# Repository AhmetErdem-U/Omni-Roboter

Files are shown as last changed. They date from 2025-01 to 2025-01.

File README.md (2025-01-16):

# **Omni-Roboter: Entwicklung eines Prototypen mit Omni-Ball-Antrieb**

## 🎯 **Projektbeschreibung**
Dieses Projekt beinhaltet die Entwicklung eines Prototyp-Roboters mit omnidirektionalem Antrieb. Der Roboter nutzt die **Omni-Ball-Technologie**, die Bewegungen in alle Richtungen ermöglicht. Das Projekt kombiniert **CAD-Konstruktion**, **3D-Druck** und **Arduino-Programmierung**, um einen funktionsfähigen Prototypen zu erstellen, der für Anwendungen in der Robotik und Automatisierung geeignet ist.

---

## 🚀 **Hauptfunktionen**
- **Omnidirektionale Bewegung:** Nahtlose Steuerung in alle Richtungen dank Omni-Ball-Technologie.
- **CAD-Konstruktion:** Präzises Design und Simulation mit Autodesk Fusion 360.
- **3D-Druck:** Mechanische Komponenten wurden aus PETG gefertigt, um eine robuste und leichte Struktur zu gewährleisten.
- **Arduino-Steuerung:** Programmierung der Motoren und Steuerlogik mit der Arduino-IDE.
- **Bluetooth-Integration:** Fernsteuerung des Roboters über ein Bluetooth-Modul.

---

## 🛠️ **Technische Details**

### **Hardware**
- **Arduino Mega 2560**
- **NEMA-17 Schrittmotoren**
- **Omni-Ball-Räder**
- **HC-05 Bluetooth-Modul**
- **LiPo-Akku**
- **RAMPS 1.4 Shield Board**

### **Software**
- **Autodesk Fusion 360:** Konstruktion der mechanischen Bauteile.
- **Arduino IDE:** Steuerung und Bewegungslogik.
- 
---

## 📸 **Bilder**

### **1. Omni-Fahrzeug**
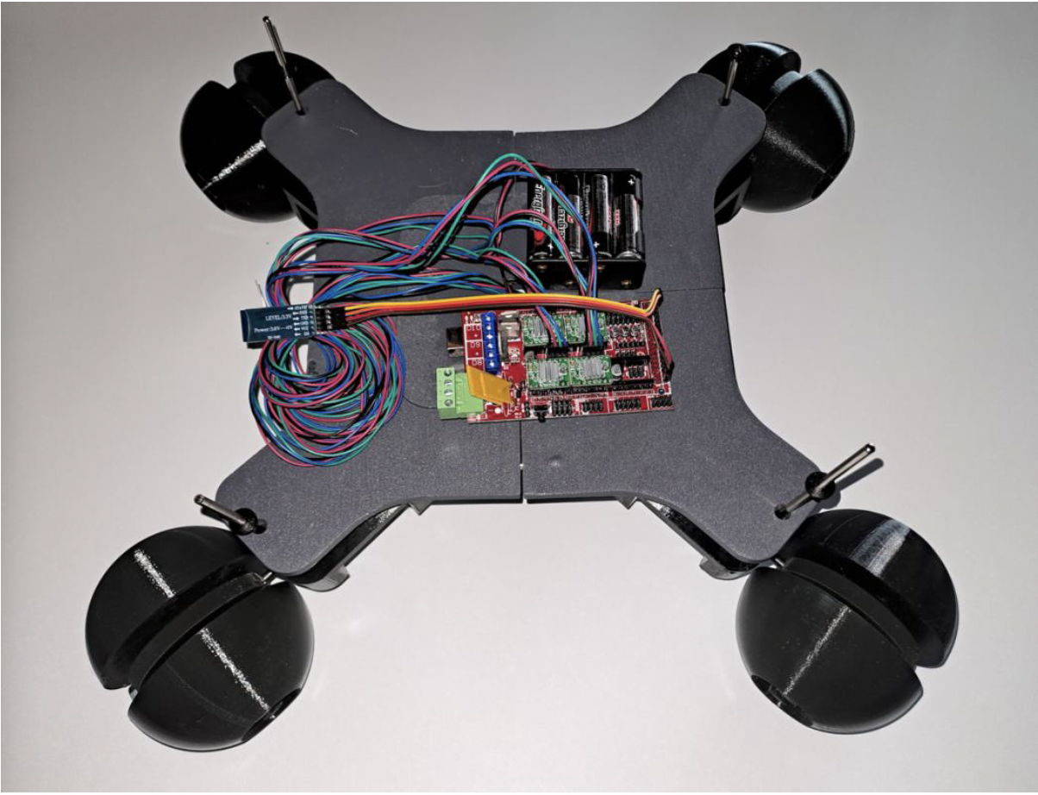
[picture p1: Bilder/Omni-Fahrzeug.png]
Omni-Roboter Bewegung


### **2. Halterung**
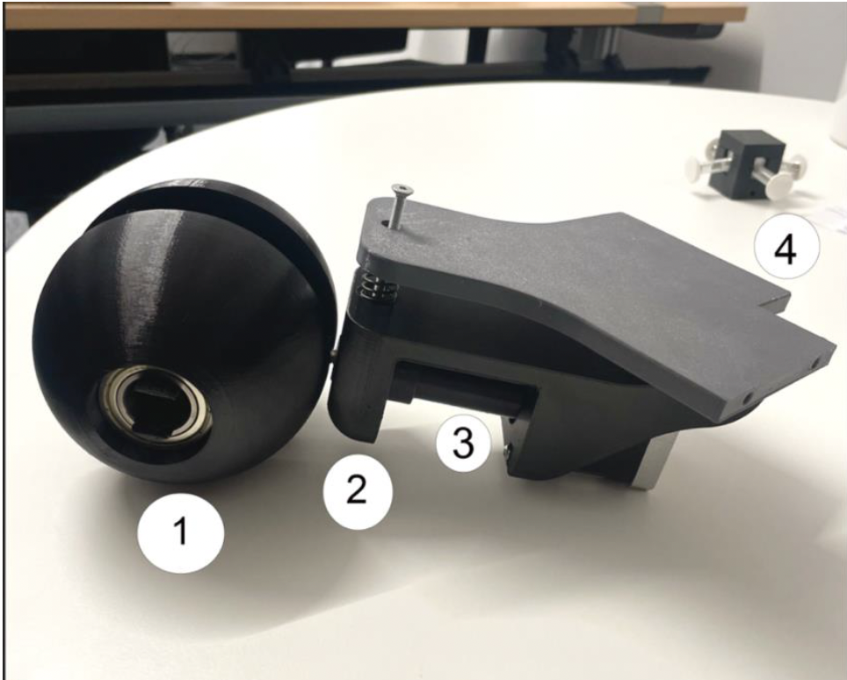
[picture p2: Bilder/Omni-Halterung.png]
Omni-Fahrzeug


### **3. Bewegungs-Verhalten**
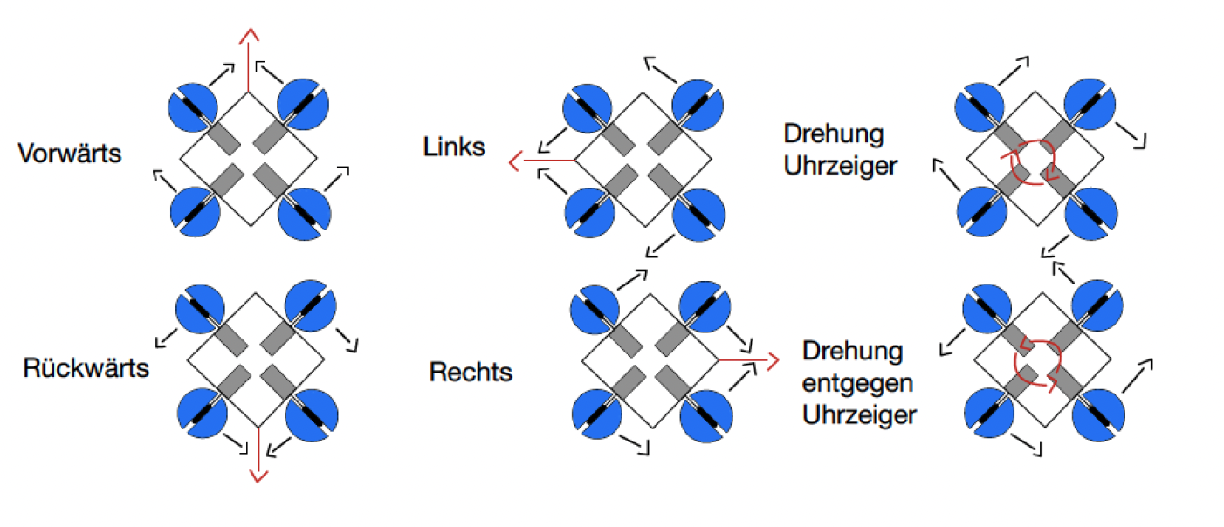
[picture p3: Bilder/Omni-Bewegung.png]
Omni Bewegung


### **4. Mechanische Details**
- **Kleine Kugel:**
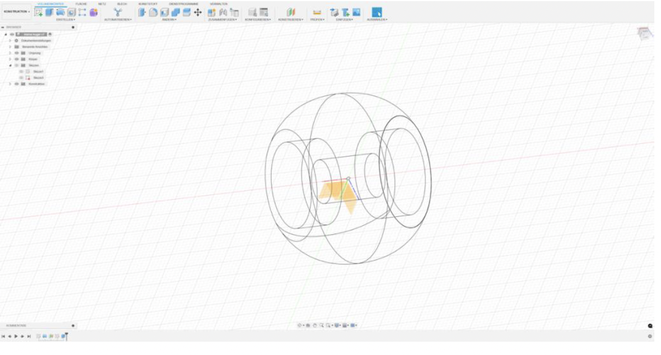
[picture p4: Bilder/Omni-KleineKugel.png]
Kleine Kugel
  

- **Hauptkugel:**
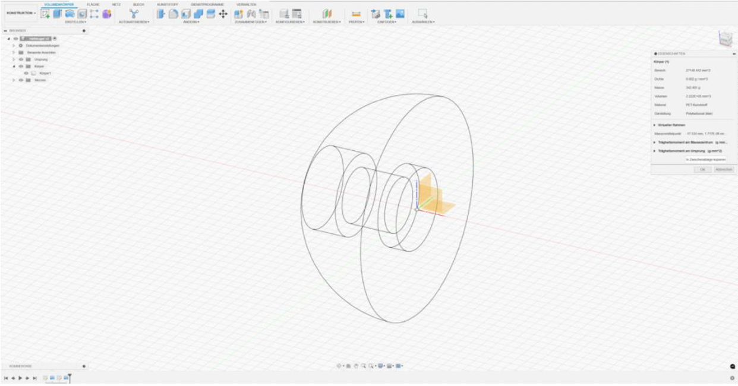
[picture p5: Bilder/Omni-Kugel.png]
Hauptkugel
  
  
- **Welle:**
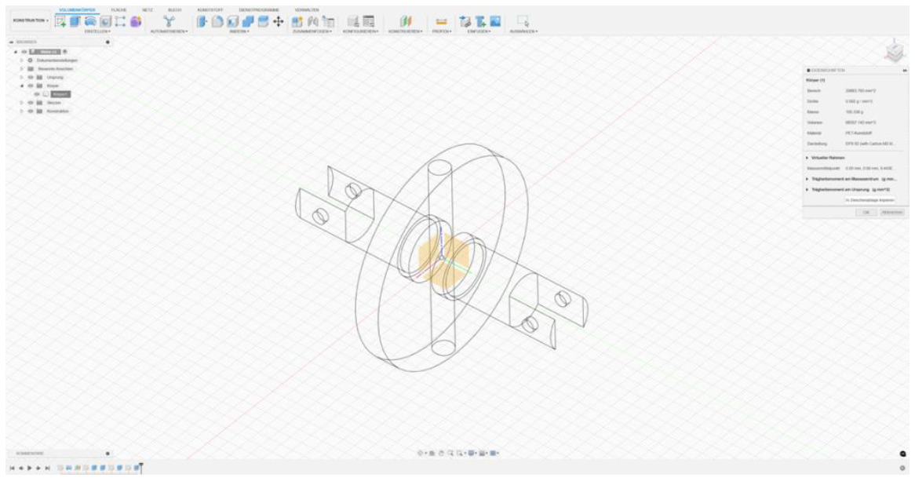
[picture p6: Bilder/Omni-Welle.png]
Welle
  

### **5. Verkabelung**
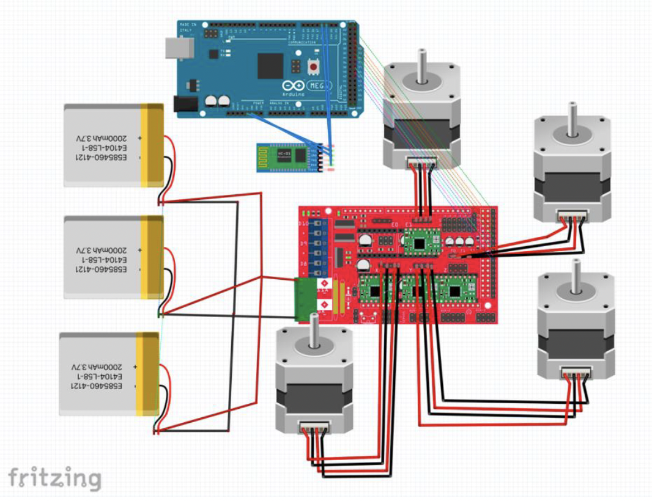
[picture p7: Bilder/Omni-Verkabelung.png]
Verkabelung


---

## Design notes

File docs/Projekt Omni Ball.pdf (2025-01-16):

Projekt Omni Ball

Komponenten für mein Projekt-Omni Ball

Mechanische Komponenten

Bauteil | Material | Abmessungen | Anzahl | Funktion
Halbkugeln | PTG (3D-gedruckt) | Durchmesser: 100 mm | 8 (jeweils 2 pro Omni-Ball) | Ermöglichen omnidirektionale Bewegung
Kleine Kugeln | PTG (3D-gedruckt) | Passend zur Oberseite der Halbkugeln | 8 (jeweils 2 pro Omni-Ball) | Unterstützung für die Halbkugeln
Welle | Edelstahl oder Aluminium | Durchmesser: 20 mm | 4 (jeweils 1 pro Omni-Ball) | Verbindung der Halbkugeln
Lager für Halbkugeln | Stahl | 37 x 20 x 9 mm | 16(jeweils 4 pro Welle) | Ermöglichen reibungslose Rotation
Lager für kleine Räder | Stahl | 10 x 5 x 4 mm | 16 (jeweils 4 pro Rad ) | Ermöglichen reibungslose Rotation
Motorhalterungen | PTG (3D-gedruckt) | Durchmesser: 42 mm | 4 (jeweils 1 pro Motor) | Befestigung der Motoren
Zahnräder (klein) | PTG (3D-gedruckt) | 12 Zähne, Durchmesser ca. 40 mm | 4 (jeweils 1 pro Motor) | Kraftübertragung vom Motor
Zahnräder (groß) | PTG (3D-gedruckt) | 30 Zähne, Durchmesser ca. 100 mm | 4 (jeweils 1 pro Welle) | Kraftübertragung zur Welle

Elektronische Komponenten

Bauteil | Typ | Spezifikationen | Anzahl | Funktion
Motoren | NEMA 17 | N/A | 4 (jeweils 1 pro Omni-
Ball)
| | | | Antrieb der Omni-Bälle

Motorsteuerungen | A4988 Motor-Treiber | N/A | 4 (jeweils 1 pro Motor) | Steuerung der Schrittmotoren
Batterien | LIPO | Spannung: 11.1V, Kapazität: 2200mAh | 3 (parallel geschaltet) | Stromversorgung
Batterie-Ladegerät | SKYRC B6AC V2 | | 1 | Ladung der Batterie
Batterie-Management | 3S 20A Li-ion Lithium Batterie BMS | | 1 | Schutz der Batterien
Arduino-Board | Arduino Mega | N/A | 1 | Zentrale Steuerungseinheit
Bluetooth-Modul | HC-05 | N/A | 1 | Drahtlose Kommunikation
Shield Board | RAMPS 1.4 Shield Board | | 1 | Erweiterung für Arduino Mega

Verbindungskomponenten

Bauteil | Typ | Spezifikationen | Anzahl | Funktion
Kabel und Steckverbinder | Jumper-Kabel, Steckverbinder | N/A | Ausreichend | Verbindungen zwischen Komponenten
Befestigungsmaterial | Schrauben, Muttern, Bolzen | N/A | Ausreichend | Befestigung der mechanischen Komponenten

Zusätzliche Materialien und Werkzeuge

Bauteil | Material/Typ | Spezifikationen Anzahl | Funktion
3D-Drucker | ABS | N/A | N/A | Herstellung von 3D-gedruckten Teilen
Superkleber | N/A | N/A | 1 Tube | Fixierung der Zahnräder an den Wellen
Werkzeuge | Schraubendreher, Zangen, Messschieber, etc. | N/A | 1 Satz | Montage der mechanischen und elektronischen Komponenten

## Vorschlag von Herr Frank: Nema Motor-Schrittmotor

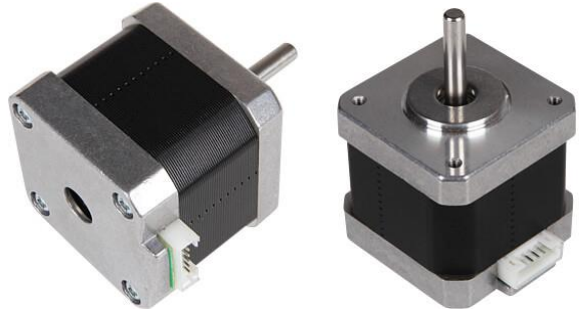
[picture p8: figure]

NEMA 17 Schrittmotor

1. Spezifikationen:
- Haltenmoment: 4.2 kg-cm (42 Ncm)
- Betriebsspannung: 12-24V
- Nennstrom: 1.2A pro Phase
- Schrittwinkel: 1.8° (200 Schritte pro Umdrehung)
- Wellenlänge: 24 mm
- Wellen-Durchmesser: 5 mm
- Abmessungen: 42 x 42 x 48 mm
2. Anzahl:
- 4 (jeweils 1 pro Omni-Ball)
3. Vorteile:
- Präzise Steuerung der Position
- Hohe Wiederholgenauigkeit
- Gute Kompatibilität mit Arduino und gängigen Treibern
4. Kompatibler Treiber:

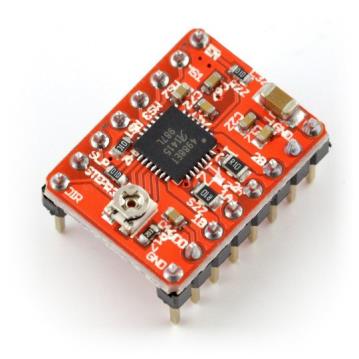
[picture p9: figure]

- A4988 Schrittmotortreiber
- Anzahl: 4 (jeweils 1 pro NEMA 17 Motor)
- Betriebsspannung: 8-35V
- Maximaler Strom: 2A pro Spule
- Microstepping: Bis zu 1/16 Schritte

Anpassungen an der Konstruktion

1. Motorhalterungen:
- Die Motorhalterungen müssen angepasst werden, um die Abmessungen des NEMA 17 Motors aufzunehmen (42 x 42 mm).
2. Zahnräder:
- Das Zahnrad für den Motor muss auf die 5 mm Welle des NEMA 17 Motors passen.
3. Elektrische Verdrahtung:
- Schrittmotortreiber (z.B. A4988) müssen in das elektrische System integriert werden, um die NEMA 17 Motoren zu steuern.

## 4. Verschiedene Batterie-Typen für das Projekt im Vergleich:

Batterietyp | Energiedichte | Lebensdauer | Sicherheit | Gewicht | Kosten
LiPo | Hoch | Mittel | Mittel | Gering | Mittel
Li-Ion | Hoch | Hoch | Hoch | Mittel | Hoch
NiMH | Niedrig | Hoch | Hoch | Hoch | Niedrig
LiFePO4 | Mittel | Sehr hoch | Sehr hoch | Mittel | Hoch
Fazit: Auswahl einer
Lipo-Batterie

5.

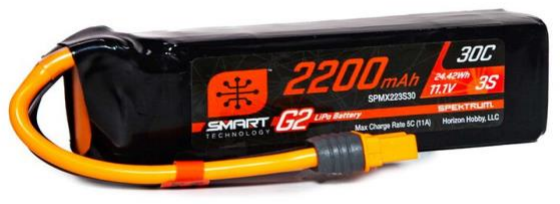
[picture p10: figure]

6. 11.1V 2200mAh 3S 30C Smart G2 LiPo Battery: IC3
7.

## 8. Arduino-Board wird von Herr Frank ausgesucht 9. Wie kann man zusätzlich eine Bluetooth Verbindung herstellen?

10. HC-05 Bluetooth-Modul: Drahtlose Kommunikation

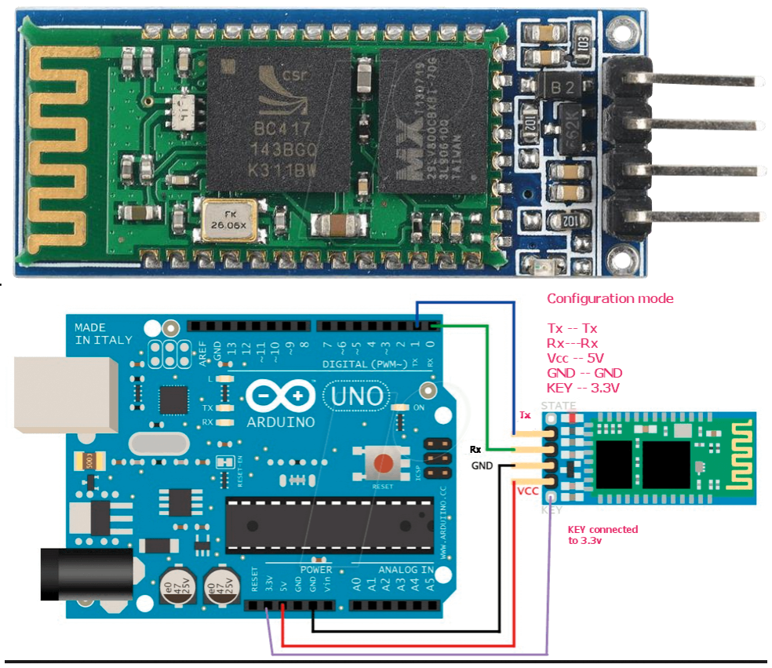
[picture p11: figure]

11.

12. ARDUINO HC-05-4 Arduino - 4duino Wireless Modul HC-05 4-Pin

Gewichtsberechnung meines Projektes

Komponente | Material/Art | Volumen (cm³) | Dichte (g/cm³) | Anzahl | Gewicht pro Einheit (g) Gesamtgewicht (g)
Omni-Ball (Halbkugeln und kleine Kugeln) | PTG (3D-gedruckt) | 313,16 | 1,04 | 4 | 325,68 | 1302,72
Welle + Stahlrohr | PTG ( 3D- gedruckt ), Sthal | 15,71 | 2,70 | 4 | 42,42 | 169,68
Lager Halbkugeln | Stahl | 10 | 7,85 | 8 | 78,5 | 628
Lager kleine Kugel | Stahl
Motoren | NEMA-17 Schrittmotor | - | - | 4 | 350 | 1400
Elektronik (Arduino, HC-05, A4988,Ramps 1.4) | Verschiedene | - | - | - | - | 300
Batterien | LiPo-Batterie (11.2V) | - | - | 2 | 500 | 1000
Kabel und Steckverbinder | Verschiedene | - | - | Ausreichend | - | 200
Befestigungsmaterial Verschiedene | | - | - | Ausreichend | - | 100
- Omni-Ball (Halbkugeln und kleine Kugeln)

- Volumen der Halbkugel:
- Das Volumen einer Halbkugel mit einem Radius von 50 mm (Durchmesser 100 mm) beträgt ca. 261,8 cm³.
- Volumen der kleinen Kugeln:
- Jede Halbkugel hat eine kleine Kugel. Ein Omni-Ball hat zwei kleine Kugeln. Wenn jede kleine Kugel 10% des Volumens einer Halbkugel hat, beträgt das Volumen jeder kleinen Kugel ca. 26,18 cm³. Somit hat ein Omni-Ball zwei kleine Kugeln mit einem Gesamtvolumen von ca. 52,36 cm³.

Gesamtvolumen des Omni-Balls:

- Das Gesamtvolumen einer Halbkugel und der kleinen Kugeln beträgt insgesamt ca. 313,16 cm³.
- Welle
- Volumen der Welle:
- Eine Welle mit einem Durchmesser von 20 mm und einer Länge von 50 mm hat ein Volumen von ca. 15,71 cm³.
- Zahnräder
- Volumen der Zahnräder:
- Das Volumen der kleinen Zahnräder wurde auf 20 cm³ und das der großen Zahnräder auf 40 cm³ festgelegt.

Berechnungen für den NEMA 17 Schrittmotor

Auf Basis der Präsentation „Wahlfach – Alternativ angetriebene Fahrzeuge“ und der Spezifikationen des NEMA 17 Schrittmotors, führen wir die relevanten Berechnungen für das Projekt durch.

### 1. Berechnung der Rollwiderstandskraft (FR)

Die Rollwiderstandskraft FR kann durch die Formel berechnet werden:

FR = m ∙ g ∙ froll

Für den NEMA 17 Schrittmotor und das Omni-Ball-Projekt benötigen wir die Masse des Systems:

- Masse des Systems (m): Nehmen wir an, die Masse beträgt 5.558 kg (5.558 kg = 5558 g / 1000).
- Gravitationskonstante (g): 9,81 m/s²
- Rollwiderstandsbeiwert (froll): Angenommen 0,015 für glatte Oberflächen.

Berechnung:

FR = 5,558 kg ∙

9,81m
s

2

- 0,015 = 0,819 N

### 2. Berechnung der Luftwiderstandskraft (FW)

Die Luftwiderstandskraft FW wird mit der Formel berechnet:

FW =

1
2
- p ∙ cW ∙ A ∙ v

2

Wir benötigen:

- Luftdichte (ρ): 1,202 kg/m³
- Luftwiderstandsbeiwert (cw): 0,3 (angenommen)
- Stirnfläche des Fahrzeugs (A): 0,1 m² (angenommen)
- Geschwindigkeit (v): 1 m/s (als Beispiel)

Berechnung:

FW =

1
2
- 1,202

kg
m³
- 0,3 ∙ 0,1m²
- (

1m
s

)

2
= 0,018 N

### 3. Berechnung der Steigungswiderstandskraft (Fsteig)

Die Steigungswiderstandskraft Fsteig wird berechnet mit:

Fsteig = m ∙ g ∙ sin (α)

Für eine Steigung von 10%:

- Steigungswinkel (α): tan⁻¹ (0,1) = 5,71°

Berechnung:

Fsteig = 5,558 kg ∙

9,81m
s

2

- sin(5,71°) = 5,42 N

### 4. Berechnung der Beschleunigungskraft (Fa)

Die Beschleunigungskraft Fa wird mit der Formel berechnet:

Fa = m ∙ a

- Beschleunigung (a): Angenommen 0,5 m/s²

Berechnung:

Fa = 5,558 kg ∙ 0,5

m
s

2

= 2,78 N

### 5. Gesamtantriebskraft (FA)

Die Gesamtantriebskraft FA ist die Summe der Widerstände:

FA = FR + FW + Fsteig + Fa

Berechnung:

FA = 0,819 N + 0,018 N + 5,42 N + 2,78N = 9,037 N

### 6. Antriebsmoment (MA)

Das Antriebsmoment MA wird mit der Formel berechnet:

MA = FA ∙ r

Rollradius (r): 0,05 m (angenommen) ,was auf dem Radius der Halbkugel basiert.

Berechnung:

MA = 9,037 N ∙ 0,05 m = 0,45185 Nm

### 7. Antriebsleistung (P)

Die Antriebsleistung P wird mit der Formel berechnet:

P = FA ∙ v

- Geschwindigkeit (v): 1 m/s

Berechnung:

P = 9,037 N ∙

1m
s

= 9,037 W

Fazit zur Eignung des NEMA 17 Schrittmotors für das Projekt

Auf Grundlage der durchgeführten Berechnungen und der technischen Daten des NEMA 17 Schrittmotors, lassen sich folgende Schlüsse ziehen:

Zusammenfassung der Berechnungen:

- Rollwiderstandskraft (FR): 0,819 N
- Luftwiderstandskraft (FW): 0,018 N
- Steigungswiderstandskraft (Fsteig): 5,42 N
- Beschleunigungskraft (Fa): 2,78 N
- Gesamtantriebskraft (FA): 9,037 N
- Antriebsmoment (MA): 0,45185 Nm
- Antriebsleistung (P): 9,037 W

Technische Spezifikationen des NEMA 17 Schrittmotors:

- Haltemoment: 4,2 kg-cm (42 Ncm oder 4,2 Nm)
- Betriebsspannung: 12-24V
- Nennstrom: 1,2A pro Phase
- Schrittwinkel: 1,8° (200 Schritte pro Umdrehung)
- Abmessungen: 42 x 42 x 48 mm

Analyse der Eignung:

1. Antriebsmoment:
- Das berechnete Antriebsmoment von 0,45185 Nm liegt deutlich unter dem Haltemoment des NEMA 17 Schrittmotors von 4,2 Nm. Dies bedeutet, dass der Motor ausreichend Kraft hat, um die erforderlichen Bewegungen auszuführen.

2. Antriebsleistung:
- Die erforderliche Antriebsleistung von 9,037 W ist relativ gering im Vergleich zu den typischen Leistungsfähigkeiten des NEMA 17 Motors, der bei den angegebenen Spannungen und Strömen wesentlich höhere Leistungen liefern kann.
3. Betriebsspannung und Nennstrom:
- Die Betriebsspannung und der Nennstrom des NEMA 17 Motors sind geeignet für den Einsatz mit den geplanten elektronischen Komponenten wie dem Arduino und den LiPo-Batterien.
4. Schrittwinkel und Präzision:
- Mit einem Schrittwinkel von 1,8° und der Möglichkeit, Mikroschritte zu nutzen, bietet der NEMA 17 Motor eine hohe Präzision und Kontrolle, die für die präzise Steuerung der Omni-Bälle wichtig ist.

Fazit:

Der NEMA 17 Schrittmotor ist ausreichend leistungsfähig und gut geeignet für das Projekt „Omni-Ball“. Er bietet ausreichend Drehmoment und Leistung, um die erforderlichen Bewegungen und Kräfte zu bewältigen. Die technischen Spezifikationen des Motors passen gut zu den Anforderungen des Projekts und den geplanten elektronischen Komponenten.

## Erweiterter Ansatz anhand eines Ramps

Methode 2: RAMPS 1.4 Shield Board mit A4988 Motor-Treiber

Komponenten:

- RAMPS 1.4 Shield: Ein Erweiterungsboard für das Arduino Mega, das speziell für die Steuerung von Schrittmotoren in 3D-Druckern entwickelt wurde. Es unterstützt bis zu fünf Pololu-Schrittmotortreiber (z.B. A4988).

A4988 Motor-Treiber: Vier Stück zur Steuerung der Schrittmotoren. Zusätzliche Kühlung der Motortreiber durch Kühlkörper alu

Vorteile:

- Integrierte Lösung: Das RAMPS 1.4 Shield vereinfacht die Verkabelung und den Anschluss der Motor-Treiber erheblich.
- Modularität: Einfacher Austausch und Upgrades der Schrittmotor-Treiber.
- Unterstützung für mehrere Motoren: Speziell für Projekte wie 3D-Drucker entwickelt, die mehrere Motoren benötigen.

Nachteile:

- Zusätzliche Komplexität bei der Programmierung: Erfordert ein Verständnis des RAMPS-Boards und möglicherweise Anpassungen an der Firmware.
- Größe: Größer als einige alternative Lösungen aufgrund des zusätzlichen Shields.

Warum ein Arduino Mega 2560 notwendig ist:

1. Kompatibilität: Das RAMPS 1.4 Shield ist speziell für das Arduino Mega 2560 entwickelt worden und passt direkt auf dieses Board.
2. I/O-Pins: Das Arduino Mega 2560 bietet genügend I/O-Pins, um alle Funktionen des RAMPS 1.4 Shields zu nutzen.
3. Leistung: Das Arduino Mega 2560 hat genügend Speicher und Rechenleistung, um komplexe Steuerungsaufgaben zu bewältigen, die mit mehreren Schrittmotoren und anderen Komponenten verbunden sind.

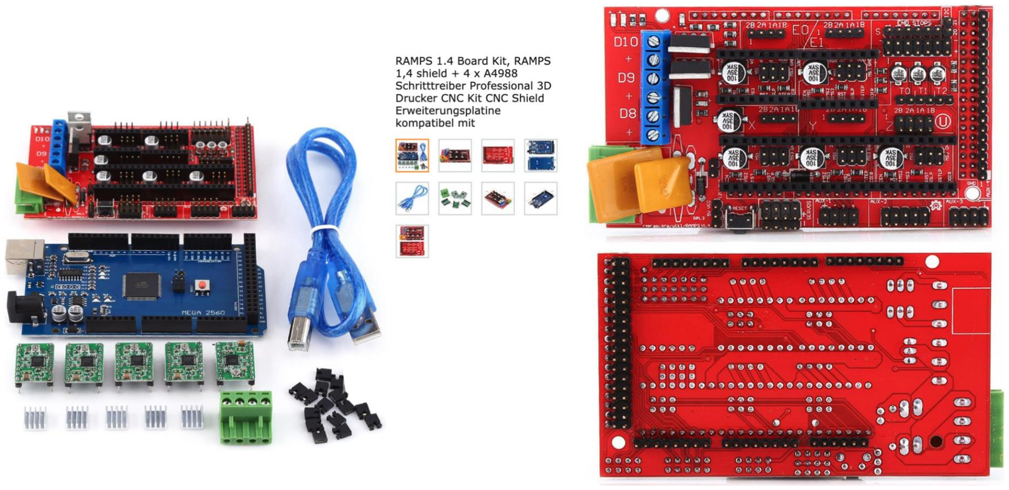
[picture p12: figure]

## Welche Lipo Batterie ist erforderlich

Anforderungen der NEMA 17 Schrittmotoren und A4988 Treiber:

- Betriebsspannung des NEMA 17: Normalerweise 12-24V.
- Strombedarf: Der NEMA 17 Schrittmotor zieht typischerweise bis zu 2A pro Phase.
- A4988 Motor-Treiber: Unterstützt eine Betriebsspannung von 8-35V und kann bis zu 2A pro Spule liefern.

Empfehlungen für LiPo-Batterien:

1. Spannung:
- Um eine Spannung innerhalb des Bereichs von 12-24V zu erreichen, könntest du zwei 3S (11.1V) oder zwei 4S (14.8V) LiPo-Batterien in Serie schalten.
- Die Serienverbindung von zwei 3S-Batterien ergibt eine Gesamtspannung von 22.2V, was innerhalb der sicheren Betriebsparameter für die A4988 Treiber liegt.
2. Kapazität:
- Die Kapazität der Batterie bestimmt, wie lange dein System betrieben werden kann. Eine Kapazität von 2200mAh oder höher wäre angemessen, um eine akzeptable Betriebsdauer zu gewährleisten.
3. Entladungsrate (C-Rate):
- Die Entladungsrate (C-Rate) sollte hoch genug sein, um den Strombedarf deines Systems zu decken. Eine C-Rate von 20C oder höher sollte ausreichen.

Beispielhafte Auswahl:

1. 3S (11.1V) 2200mAh 30C LiPo-Batterie:
- Spannung: 11.1V
- Kapazität: 2200mAh
- Entladungsrate: 30C
- Anzahl: 3 in Serie für 22.2V

Ladegrät: SKYRC B6AC V2

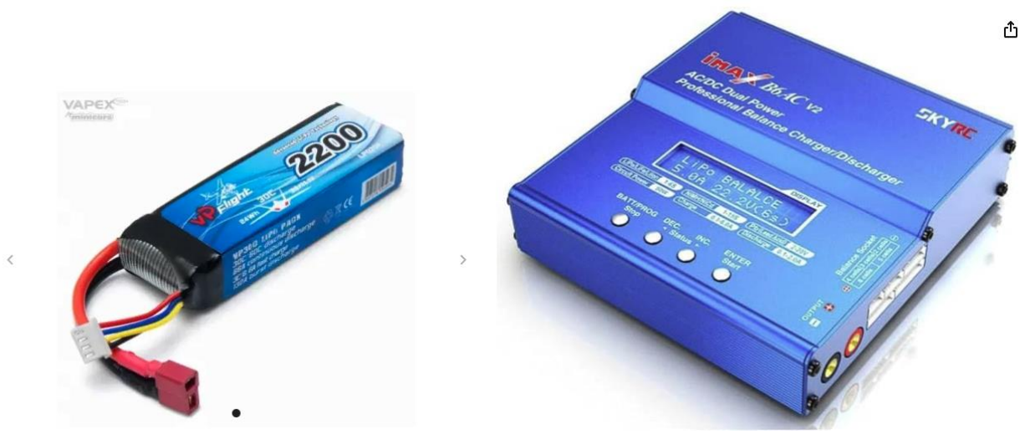
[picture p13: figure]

Vorteile des 3S 20A Li-ion Lithium BMS:

- Schutzfunktionen: Bietet Schutz vor Überladung, Tiefentladung, Überstrom und Kurzschluss.
- Balancer-Funktion: Stellt sicher, dass die Spannung der einzelnen Zellen ausgeglichen wird, um die Lebensdauer der Batterien zu maximieren.
- Stromkapazität: Unterstützt bis zu 20A, was für dein Projekt mit NEMA 17 Schrittmotoren und A4988 Motor-Treibern ausreichend sein sollte.

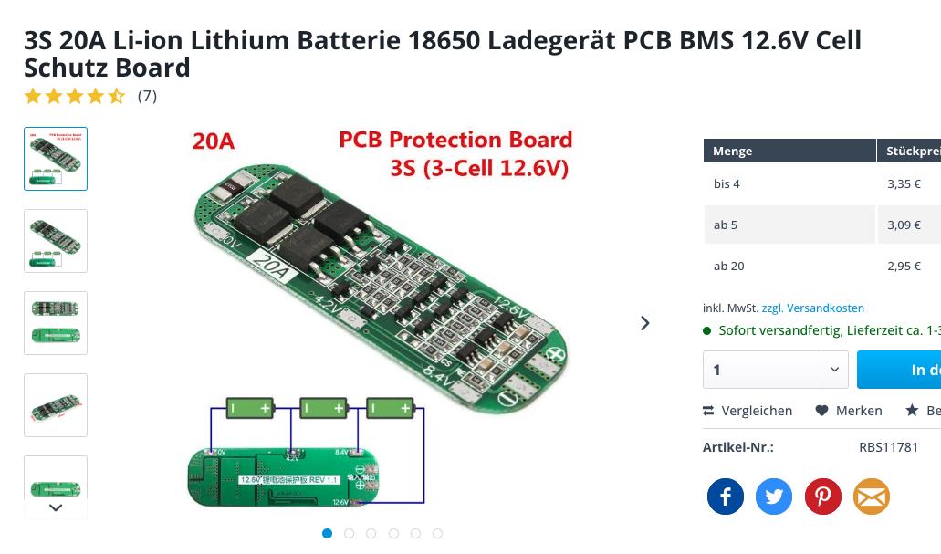
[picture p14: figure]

Ein einzelnes 3S-Batteriepaket (drei in Serie geschaltete 3S 11.1V 2200mAh 30C LiPo-Batterien) kann die Anforderungen des Systems erfüllen, aber die Laufzeit wäre begrenzt

Leistungsanforderungen:

- Einzelner NEMA 17 Schrittmotor: Bis zu 2A pro Phase, maximal 4A pro Motor.
- Vier NEMA 17 Schrittmotoren: 4 Motoren x 4A= 16 A

Batterie-Kapazität:

- 3S 11.1V 2200mAh 30C LiPo-Batterie:
- Nennspannung: 11.1V
- Maximale Spannung: 12.6V
- Kapazität: 2200mAh (2.2Ah)
- Entladestrom: 2200mAh x 30C = 66A

Laufzeitberechnung:

- Kapazität: 2200mAh (2.2Ah)
- Gesamtstrombedarf: 16A

Laufzeit=Kapazität/Gesamt-Strom = 2,2 Ah / 16 A = 0,1375 Stunden = 8,25 Minuten

Fazit:

Ein einzelnes 3S-Batteriepaket wäre in der Lage, die vier NEMA 17 Schrittmotoren zu betreiben, jedoch nur für eine sehr kurze Zeit von etwa 8 Minuten bei voller Last.

Empfehlungen / Verbesserung:

Um eine längere Laufzeit zu erreichen, wäre es sinnvoll, mehrere 3S-Batteriepakete parallel zu schalten. Jede zusätzliche Parallelschaltung verdoppelt die Kapazität und damit die Laufzeit.

Komponenten für ein 3S-Batteriepaket:

1. 3 x 3.7V Li-ion oder LiPo-Zellen: Jede Zelle hat eine Nennspannung von 3.7V und eine Kapazität von 2200mAh (2.2Ah).
- Produkt: 3S 11.1V 2200mAh 30C LiPo-Batterien
- Einkaufsquelle: 3S 11.1V 2200mAh 30C LiPo-Batterien auf Amazon

2. 1 x 3S 20A Li-ion Lithium Batterie BMS: Das BMS verwaltet die Ladung und den Entladestrom und schützt die Batterien vor Überladung, Tiefentladung und Kurzschluss.
- Produkt: 3S 20A Li-ion Lithium Batterie BMS
3. SKYRC B6AC V2 Ladegerät:

Komponentenliste:

1. 4 NEMA 17 Motoren
2. 4 A4988 Motortreiber
3. 1 RAMPS 1.4 Shield Board
4. 1 Arduino Mega
5. 3 3S 11.1V 2200mAh 30C LiPo-Batterien
6. 1 3S 20A Li-ion Lithium Batterie BMS
7. 1 SKYRC B6AC V2 Ladegerät

Überprüfung der Kompatibilität und Funktionalität:

1. NEMA 17 Motoren:
- Betriebsspannung: 12-24V
- Strombedarf: Bis zu 2A pro Phase, maximal 4A pro Motor
2. A4988 Motortreiber:
- Betriebsspannung: 8-35V
- Stromhandling: Bis zu 2A pro Phase (mit Kühlung)
3. RAMPS 1.4 Shield Board:
- Kompatibilität: Entwickelt für das Arduino Mega 2560
- Anschlüsse: Unterstützt bis zu 5 Schrittmotor-Treiber

4. Arduino Mega:
- Kompatibilität: Kompatibel mit RAMPS 1.4 Shield
- Programmierbarkeit: Unterstützt die Arduino IDE und Steuerung der A4988 Treiber
5. 3 x 3S 11.1V 2200mAh 30C LiPo-Batterien:
- Gesamtspannung in Serie: 33.3V (11.1V x 3)
- Kapazität: 2200mAh (2.2Ah)
- Entladestrom: 2200mAh x 30C = 66A
6. 3S 20A Li-ion Lithium Batterie BMS:
- Maximaler Strom: 20A
- Zellspannung: Entwickelt für 3S (12.6V voll geladen)
7. SKYRC B6AC V2 Ladegerät:
- Unterstützte Batterietypen: LiPo, LiFePO4, LiIon, NiMH, NiCd, Blei
- Ladestrom: Bis zu 6A
- Balancer-Funktion: Ja

Konfiguration und Bewertung:

Strom- und Spannungsanforderungen:

- NEMA 17 Motoren: Die Motoren benötigen eine Spannung von 12-24V.
- 3S-Konfiguration: Jede 3S-Batterie liefert 11.1V (nominal), 12.6V (voll geladen). Wenn drei 3S-Batterien in Serie geschaltet werden, ergibt das 33.3V, was zu hoch ist für die A4988 Motortreiber (maximal 35V, aber sehr nah an der Grenze).
- Empfohlene Konfiguration: Parallelschaltung der 3S-Batterien statt Serie, um innerhalb der Spannungsgrenzen zu bleiben und die Kapazität zu erhöhen.

Parallelschaltung der Batterien:

- Parallelschaltung der drei 3S-Batterien: Spannung bleibt bei 11.1V (nominal), 12.6V (voll geladen), Kapazität erhöht sich auf 6600mAh (6.6Ah).
- Stromversorgung: Das 3S 20A BMS kann den maximalen Strombedarf von 16A unterstützen.

Verbindung zum RAMPS 1.4 Shield:

- Stromversorgung des Shields: 11.1V (nominal) von den parallel geschalteten 3S-Batterien.
- Motortreiberanschlüsse: Die A4988 Motortreiber werden auf das RAMPS 1.4 Shield gesteckt und sind für die Ansteuerung der NEMA 17 Motoren konfiguriert.

Gesamtkonfiguration:

- Arduino Mega: Wird auf das RAMPS 1.4 Shield gesteckt.
- RAMPS 1.4 Shield: Unterstützt die Steuerung der vier A4988 Motortreiber und NEMA 17 Motoren.
- 3S 20A BMS: Verbindet die parallel geschalteten 3S-Batterien und bietet Schutz.

Beispiel für die Verkabelung:

Batterien:

Batterie 1: + (B+) ----> + (B+)
- (B-) ----> - (B-)

Batterie 2: + (B+) ----> + (B+)
- (B-) ----> - (B-)

Batterie 3: + (B+) ----> + (B+)
- (B-) ----> - (B-)
- Verbinde die positiven Pole der Batterien miteinander und mit dem B+ Anschluss des BMS.
- Verbinde die negativen Pole der Batterien miteinander und mit dem B- Anschluss des BMS.

BMS-Anschlüsse:

- B-: Verbinde den negativen Pol der ersten Batterie.
- B1: Verbinde den Punkt zwischen der ersten und zweiten Batterie.
- B2: Verbinde den Punkt zwischen der zweiten und dritten Batterie.
- B+: Verbinde den positiven Pol der dritten Batterie.

Verbindung zum RAMPS 1.4 Shield:

- Stromversorgung: Verbinde die Ausgänge des BMS (B+ und B-) mit den entsprechenden Eingängen des RAMPS 1.4 Shields.

Zusammenfassung:

- Spannung und Strom: Die parallel geschalteten 3S-Batterien liefern eine ausreichende Spannung und Kapazität.
- BMS: Das 3S 20A BMS bietet ausreichenden Schutz und Strommanagement.
- Motortreiber: Die A4988 Motortreiber sind kompatibel und können die NEMA 17 Motoren steuern.
- Gesamtsetup: Die Komponenten sind kompatibel und sollten zusammenarbeiten, um dein Projekt zu betreiben.

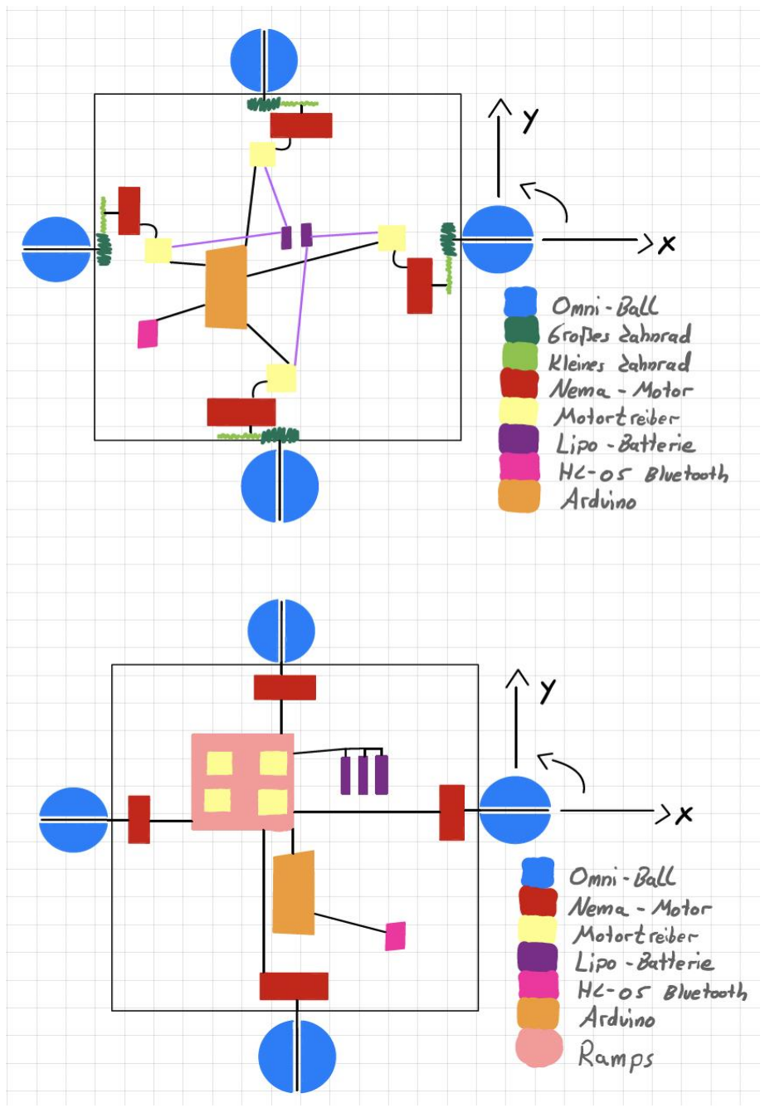
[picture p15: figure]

Verkabelungsschritte:

Schritt 1: Vorbereitung der LiPo-Batterien

- In Serie schalten: Verbinde die Batterien in Serie, um eine Gesamtspannung von 11.1V zu erhalten.
- Verbindung: + der ersten Batterie mit - der zweiten Batterie, + der zweiten Batterie mit - der dritten Batterie.
- Ausgänge: Der - Anschluss der ersten Batterie und der + Anschluss der dritten Batterie werden die Ausgangsleitungen sein.

Schritt 2: Verbindung der Batterien zum RAMPS 1.4 Shield

- Power Anschluss: Verbinde die Ausgangsleitungen der in Serie geschalteten Batterien mit dem Power-Anschluss des RAMPS 1.4 Shields (12-35V IN).

Schritt 3: Verbindung der A4988 Motortreiber zum RAMPS 1.4 Shield

- Einsetzen der A4988 Treiber: Setze die A4988 Motortreiber in die entsprechenden Steckplätze des RAMPS 1.4 Shields ein. Achte darauf, dass die Orientierung korrekt ist (VREF Pin zu den Kondensatoren).

Schritt 4: Verbindung der NEMA 17 Motoren zu den A4988 Treibern

- Motoranschlüsse:
- Motor 1 (X): Verbinde A+, A-, B+, B- des Motors mit 1A, 1B, 2A, 2B des A4988 Treibers im X-Steckplatz.
- Motor 2 (Y): Verbinde A+, A-, B+, B- des Motors mit 1A, 1B, 2A, 2B des A4988 Treibers im Y-Steckplatz.
- Motor 3 (Z): Verbinde A+, A-, B+, B- des Motors mit 1A, 1B, 2A, 2B des A4988 Treibers im Z-Steckplatz.
- Motor 4 (E1): Verbinde A+, A-, B+, B- des Motors mit 1A, 1B, 2A, 2B des A4988 Treibers im E1-Steckplatz.

Schritt 5: Verbindung des RAMPS 1.4 Shields zum Arduino Mega

- Steckverbindung: Stecke das RAMPS 1.4 Shield auf das Arduino Mega Board. Alle Pins sollten automatisch verbunden sein.

Schritt 6: Verbindung des HC-05 Bluetooth Moduls zum Arduino Mega

- HC-05 Pinout:
- VCC: Verbinde VCC des HC-05 zu 5V des Arduino Mega.
- GND: Verbinde GND des HC-05 zu GND des Arduino Mega.
- TXD: Verbinde TXD des HC-05 zu RX (z.B. D19) des Arduino Mega (ggf. über einen Spannungsteiler, um die Spannung auf 3.3V zu senken).
- RXD: Verbinde RXD des HC-05 zu TX (z.B. D18) des Arduino Mega.

Platzierung der Komponenten auf dem Breadboard (optional)

- Breadboard Verwendung: Du kannst das Breadboard verwenden, um vorläufige Verbindungen zu testen und sicherzustellen, dass alle Komponenten korrekt arbeiten, bevor du die endgültigen Verbindungen herstellst.

Schaltplan

Hier ist eine schematische Darstellung, wie die Verbindungen aussehen sollten:

scss
Code kopieren
[LiPo Batterie 1 (+)] --> [LiPo Batterie 2 (-)] [LiPo Batterie 2 (+)] --> [LiPo Batterie 3 (-)] [LiPo Batterie 1 (-)] --> [GND (RAMPS Power In)] [LiPo Batterie 3 (+)] --> [12V (RAMPS Power In)]

[A4988 Treiber (X)] --> [NEMA 17 Motor 1] [A4988 Treiber (Y)] --> [NEMA 17 Motor 2] [A4988 Treiber (Z)] --> [NEMA 17 Motor 3] [A4988 Treiber (E1)] --> [NEMA 17 Motor 4]

[RAMPS 1.4 Shield] --> [Arduino Mega]

[HC-05 Bluetooth Modul]
VCC --> 5V (Arduino Mega)
GND --> GND (Arduino Mega)

TXD --> RX (Arduino Mega, z.B. D19) RXD --> TX (Arduino Mega, z.B. D18)

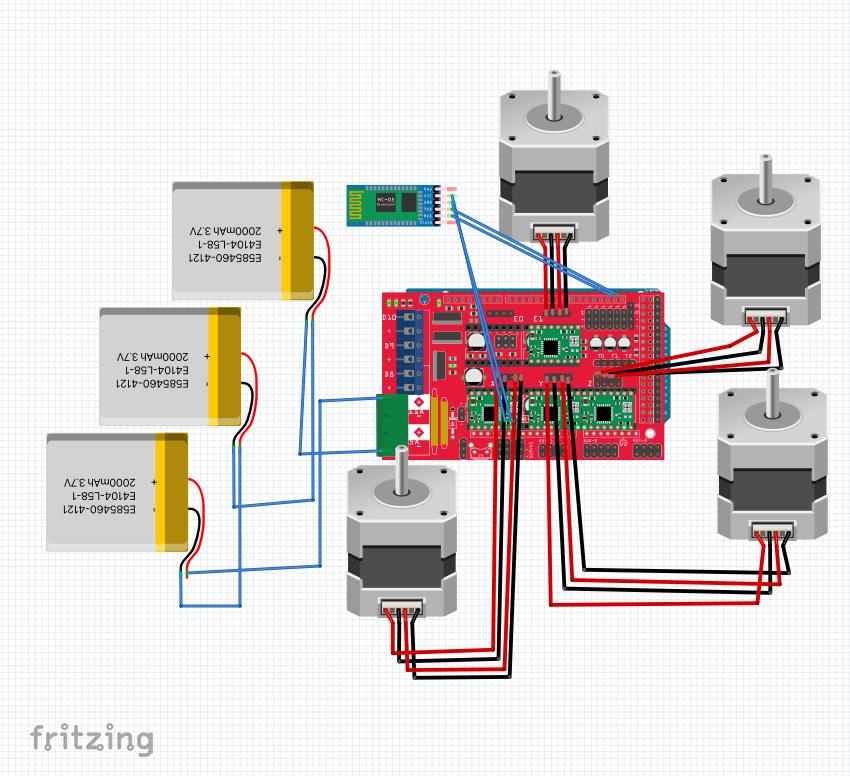
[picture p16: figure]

Verbindungen der Komponenten:

Arduino Mega zu RAMPS 1.4 Shield:

1. Power Pins:
- VIN (Arduino Mega) zu VIN (RAMPS 1.4)
- GND (Arduino Mega) zu GND (RAMPS 1.4)
2. Motorsteuerungen:
- X-Motor:
- STEP Pin zu Pin 54 (D2)
- DIR Pin zu Pin 55 (D3)
- Y-Motor:
- STEP Pin zu Pin 60 (D26)
- DIR Pin zu Pin 61 (D28)
- Z-Motor:
- STEP Pin zu Pin 46 (D36)
- DIR Pin zu Pin 48 (D34)
- E-Motor (Extruder):
- STEP Pin zu Pin 26 (D36)
- DIR Pin zu Pin 28 (D34)

Motoren zu A4988 Motortreiber:

1. X-Motor:
- Motor A+ zu 2A (A4988)
- Motor A- zu 2B (A4988)
- Motor B+ zu 1A (A4988)

- Motor B- zu 1B (A4988)
2. Y-Motor:
- Motor A+ zu 2A (A4988)
- Motor A- zu 2B (A4988)
- Motor B+ zu 1A (A4988)
- Motor B- zu 1B (A4988)
3. Z-Motor:
- Motor A+ zu 2A (A4988)
- Motor A- zu 2B (A4988)
- Motor B+ zu 1A (A4988)
- Motor B- zu 1B (A4988)
4. E-Motor (Extruder):
- Motor A+ zu 2A (A4988)
- Motor A- zu 2B (A4988)
- Motor B+ zu 1A (A4988)
- Motor B- zu 1B (A4988)

Stromversorgung:

1. 12V und GND:
- Minuspol der ersten Batterie zu GND (RAMPS 1.4)
- Pluspol der letzten Batterie zu +12V (RAMPS 1.4)

Bluetooth-Modul HC-05:

1. Verbindungen zu Arduino Mega:
- VCC zu 5V
- GND zu GND
- TXD zu RX (Pin 0)
- RXD zu TX (Pin 1)

Hinweis für Batterien:

- Stelle sicher, dass die Batterien korrekt in Serie geschaltet sind, bevor du die Verbindungen zum RAMPS 1.4 Board herstellst.

Zusammenfassung der Verbindungen:

- Arduino Mega:
- VIN und GND zu RAMPS 1.4
- Motoren:
- X, Y, Z und Extruder-Motoren zu entsprechenden A4988 Motortreibern
- A4988 Motortreiber:
- Verbindungen zu STEP und DIR Pins auf RAMPS 1.4
- Stromversorgung:
- 12V und GND Verbindungen zu den Schraubklemmen auf RAMPS 1.4
- Bluetooth-Modul HC-05:
- VCC, GND, TXD, RXD Verbindungen zu Arduino Mega

Funktionen der Pins

Komponente | Pin | Funktion | Typ
Arduino Mega | VIN | Stromversorgung zum RAMPS 1.4 Shield | Strom
| GND | Masseverbindung zum RAMPS 1.4 Shield | Strom
| Pin 54 (D2) | STEP-Signal für X-Motor | Digital
| Pin 55 (D3) | DIR-Signal für X-Motor | Digital
| Pin 60 (D26) | STEP-Signal für Y-Motor | Digital
| Pin 61 (D28) | DIR-Signal für Y-Motor | Digital

| Pin 46 (D36) | STEP-Signal für Z-Motor | Digital
| Pin 48 (D34) | DIR-Signal für Z-Motor | Digital
| Pin 26 (D36) | STEP-Signal für E-Motor | Digital
| Pin 28 (D34) | DIR-Signal für E-Motor | Digital
| RX (Pin 0) | Empfang vom Bluetooth-Modul HC-05 | Digital
| TX (Pin 1) | Senden zum Bluetooth-Modul HC-05 | Digital
| 5V | Stromversorgung für das Bluetooth-Modul HC-05 | Strom
| GND | Masseverbindung für das Bluetooth-Modul HC-05 | Strom
RAMPS 1.4 Shield | +12V | Stromversorgung (+) von den Batterien | Strom
| GND | Masseverbindung (-) von den Batterien | Strom
| D2 (X-STEP) | STEP-Signal für X-Motor | Digital
| D3 (X-DIR) | DIR-Signal für X-Motor | Digital
| D26 (Y-STEP) | STEP-Signal für Y-Motor | Digital
| D28 (Y-DIR) | DIR-Signal für Y-Motor | Digital
| D36 (Z-STEP) | STEP-Signal für Z-Motor | Digital
| D34 (Z-DIR) | DIR-Signal für Z-Motor | Digital
| D36 (E-STEP) | STEP-Signal für E-Motor | Digital
| D34 (E-DIR) | DIR-Signal für E-Motor | Digital
A4988 Motortreiber | STEP | Verbindung zu STEP-Pin des entsprechenden Motors | Motor
| DIR | Verbindung zu DIR-Pin des entsprechenden Motors | Motor
| 2A, 2B, 1A, 1B | Anschlüsse für die Motorwicklungen | Motor
Bluetooth-Modul HC-05 | VCC | 5V Stromversorgung vom Arduino | Strom
| GND | Masseverbindung zum Arduino | Strom
| TXD | Verbindung zu RX (Pin 0) des Arduino | Digital
| RXD | Verbindung zu TX (Pin 1) des Arduino | Digital

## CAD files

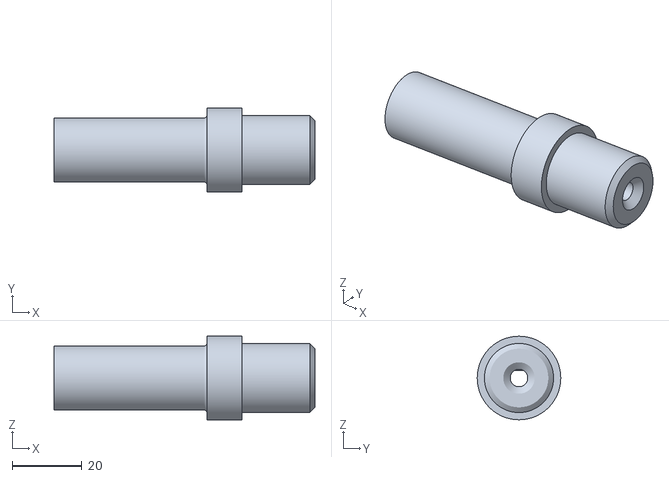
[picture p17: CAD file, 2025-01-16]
cad/Achsadapter_V4.stl
75.0 x 24.0 x 24.0

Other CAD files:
cad/Halbkugel v3_step.prt
cad/Welle v6_step.prt
cad/kleine kugel v8_step.prt

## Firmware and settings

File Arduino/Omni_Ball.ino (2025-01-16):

// Pin-Zuweisung für das RAMPS 1.4 Shield Board

#define stepPinX 54  // STEP Pin für X-Achse (Arduino Pin D2)
#define dirPinX 55   // DIR Pin für X-Achse (Arduino Pin D3)
#define stepPinY 60  // STEP Pin für Y-Achse (Arduino Pin D26)
#define dirPinY 61   // DIR Pin für Y-Achse (Arduino Pin D28)
#define stepPinZ 46  // STEP Pin für Z-Achse (Arduino Pin D36)
#define dirPinZ 48   // DIR Pin für Z-Achse (Arduino Pin D34)
#define stepPinE 26  // STEP Pin für E-Achse (Arduino Pin D36)
#define dirPinE 28   // DIR Pin für E-Achse (Arduino Pin D34)

// Bluetooth HC-05
#define bluetoothRX 0  // RX Pin des Arduino Mega (Arduino Pin RX0)
#define bluetoothTX 1  // TX Pin des Arduino Mega (Arduino Pin TX0)

// Schrittweite (Anzahl Schritte pro Umdrehung)
const int stepsPerRevolution = 200;  // Beispielwert, anpassen je nach Motor

void setup() {
  // STEP- und DIR-Pins als Ausgang definieren
  pinMode(stepPinX, OUTPUT);
  pinMode(dirPinX, OUTPUT);
  pinMode(stepPinY, OUTPUT);
  pinMode(dirPinY, OUTPUT);
  pinMode(stepPinZ, OUTPUT);
  pinMode(dirPinZ, OUTPUT);
  pinMode(stepPinE, OUTPUT);
  pinMode(dirPinE, OUTPUT);

  // Initialisierung der seriellen Kommunikation für das Bluetooth-Modul
  Serial.begin(9600);  // Start der seriellen Kommunikation bei 9600 Baud
}

// Funktion zur Steuerung eines Motors
void moveMotor(int stepPin, int dirPin, int steps, bool direction) {
  digitalWrite(dirPin, direction);  // Setze die Drehrichtung
  for (int i = 0; i < steps; i++) {
    digitalWrite(stepPin, HIGH);
    delayMicroseconds(1000);  // Bestimmt die Geschwindigkeit
    digitalWrite(stepPin, LOW);
    delayMicroseconds(1000);
  }
}

// Vorwärtsbewegung
void forward() {
  moveMotor(stepPinX, dirPinX, stepsPerRevolution, true);
  moveMotor(stepPinY, dirPinY, stepsPerRevolution, true);
  moveMotor(stepPinZ, dirPinZ, stepsPerRevolution, true);
  moveMotor(stepPinE, dirPinE, stepsPerRevolution, true);
}
// Rückwärtsbewegung
void backward() {
  moveMotor(stepPinX, dirPinX, stepsPerRevolution, false);
  moveMotor(stepPinY, dirPinY, stepsPerRevolution, false);
  moveMotor(stepPinZ, dirPinZ, stepsPerRevolution, false);
  moveMotor(stepPinE, dirPinE, stepsPerRevolution, false);
}
// Linksbewegung
void left() {
  moveMotor(stepPinX, dirPinX, stepsPerRevolution, false);
  moveMotor(stepPinY, dirPinY, stepsPerRevolution, true);
  moveMotor(stepPinZ, dirPinZ, stepsPerRevolution, false);
  moveMotor(stepPinE, dirPinE, stepsPerRevolution, true);
}
// Rechtsbewegung
void right() {
  moveMotor(stepPinX, dirPinX, stepsPerRevolution, true);
  moveMotor(stepPinY, dirPinY, stepsPerRevolution, false);
  moveMotor(stepPinZ, dirPinZ, stepsPerRevolution, true);
  moveMotor(stepPinE, dirPinE, stepsPerRevolution, false);
}
// Drehung im Uhrzeigersinn (CW)
void rotateCW() {
  moveMotor(stepPinX, dirPinX, stepsPerRevolution, true);
  moveMotor(stepPinY, dirPinY, stepsPerRevolution, true);
  moveMotor(stepPinZ, dirPinZ, stepsPerRevolution, false);
  moveMotor(stepPinE, dirPinE, stepsPerRevolution, false);
}
// Drehung gegen den Uhrzeigersinn (CCW)
void rotateCCW() {
  moveMotor(stepPinX, dirPinX, stepsPerRevolution, false);
  moveMotor(stepPinY, dirPinY, stepsPerRevolution, false);
  moveMotor(stepPinZ, dirPinZ, stepsPerRevolution, true);
  moveMotor(stepPinE, dirPinE, stepsPerRevolution, true);
}

void loop() {
  if (Serial.available() > 0) {
    char command = Serial.read();  // Lese den empfangenen Befehl

    switch (command) {
      case 'F':  // Vorwärts
        forward();
        break;
      case 'B':  // Rückwärts
        backward();
        break;
      case 'L':  // Links
        left();
        break;
      case 'R':  // Rechts
        right();
        break;
      case 'C':  // Drehung im Uhrzeigersinn (CW)
        rotateCW();
        break;
      case 'A':  // Drehung gegen den Uhrzeigersinn (CCW)
        rotateCCW();
        break;
    }
  }
}

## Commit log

2025-01-16 Add Folder cad
2025-01-16 Arduino Folder
